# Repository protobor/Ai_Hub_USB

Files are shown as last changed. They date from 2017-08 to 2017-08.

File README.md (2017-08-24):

fe1.1s hub
==========

cloned from https://github.com/acrobotic/Ai_Hub_USB

Fork
----

 * completely redesigned
 * added support for gang power control (tested, ok)
 * will correctly switch between bus power and external power (self powered signal is inverted)

Issues
------

 * MOSFET footprint is fu...., so to assembly you'll need to bend legs and solder it upside down;
 * Something wrong with milling for usb micro b connector;
 * Bus powered and self powered signals inverted.

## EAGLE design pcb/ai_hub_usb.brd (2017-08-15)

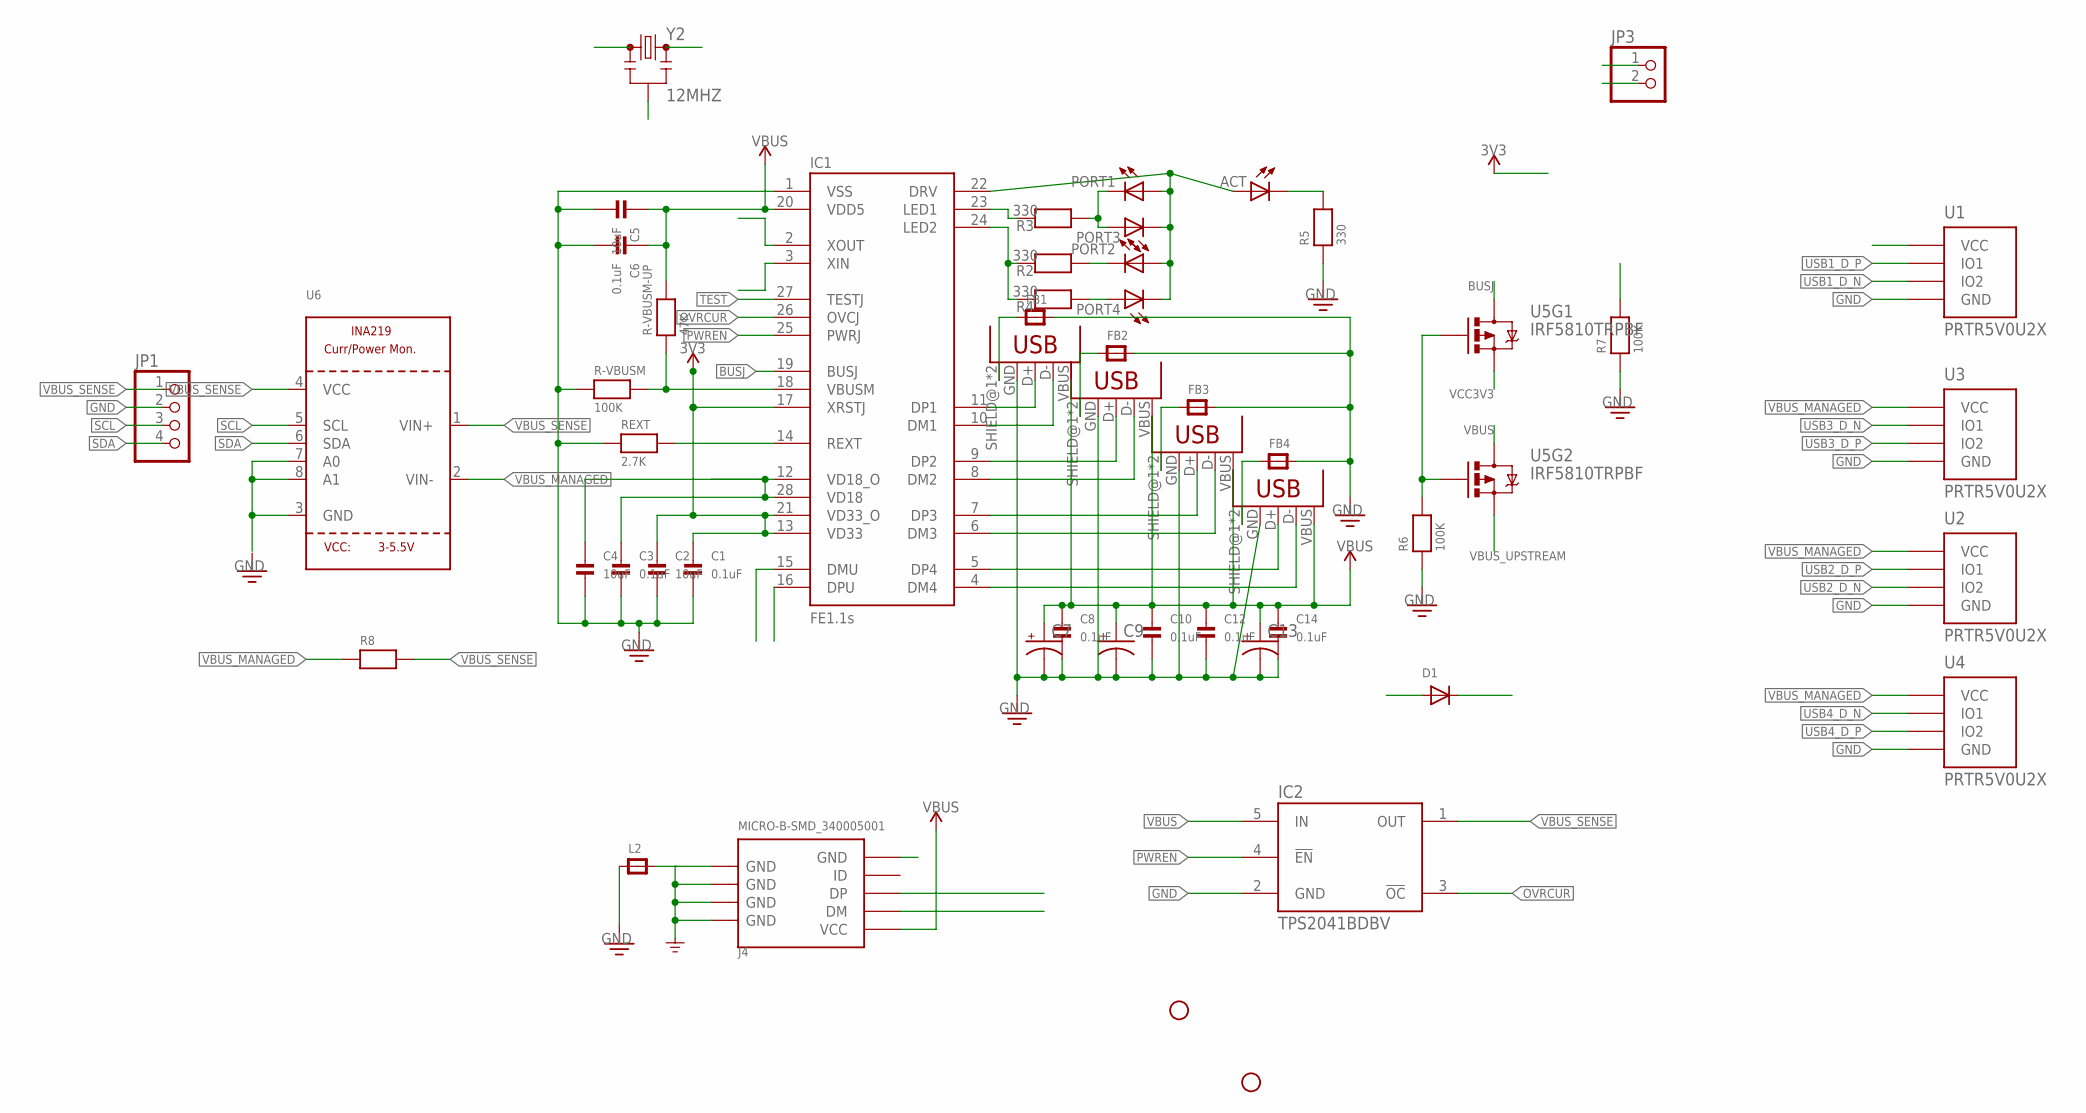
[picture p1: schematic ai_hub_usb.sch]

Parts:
ACT: LED0603; LED-0603
C1, C3, C6, C8, C10, C12, C14: 0.1uF; _0603MP
C2, C4, C5: 10uF; _0603MP
C7, C9, C13: CAP_POLD; PANASONIC_D
D1: DIODESMA; SMADIODE
FB1, FB2, FB3, FB4: FERRITE_0603MP; _0603MP
IC1: FE1.1S; FE1.1S_SSOP-28
IC2: TPS2041BDBV; SOT23-5L
J4: MICRO-B-SMD_340005001; MICRO-USB
JP1: HEADER-1X4ROUND; 1X04_ROUND
JP3: HEADER-1X2ROUND; 1X02_ROUND
L2: FERRITE_0603MP; _0603MP
PORT1, PORT2, PORT3, PORT4: LED0603; LED-0603
R2, R3, R4, R5: 330; _0603MP
R6, R7: 100K; _0603MP
R8: RESISTOR1206; 1206
R-VBUSM: 100K; _0603MP
R-VBUSM-UP: 47K; _0603MP
REXT: 2.7K; _0603MP
STANDOFF1, STANDOFF4: STAND-OFF4; STAND-OFF-4
U1, U2, U3, U4: PRTR5V0U2X; SOT-143B
U5: IRF5810TRPBF; SOT23-6
U6: INA219; SOT23-8
USB1, USB3, USB4: USBA-PTH-VERTICAL; USB-A-F-PTH-VERTICAL
USB2: USBA-PTH; USB-A-F-PTH
Y2: 12MHZ; RESONATOR-SMD

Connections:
BUSJ: IC1.19 (BUSJ), R7.2, U5.6 (D)
DRV: ACT.A, IC1.22 (DRV), PORT1.A, PORT2.A, PORT3.C, PORT4.C
GND: C1.2, C2.2, C3.2, C4.2, C5.2, C6.2, C7.-, C8.2, C9.-, C10.2, C12.2, C13.-, C14.2, FB1.2, FB2.2, FB3.2, FB4.2, IC1.1 (VSS), IC2.2 (GND), J4.5 (GND), JP1.2, JP3.2, L2.1, R5.1, R6.1, R7.1, R-VBUSM.1, REXT.1, U1.1 (GND), U2.1 (GND), U3.1 (GND), U4.1 (GND), U6.3 (GND), U6.7 (A0), U6.8 (A1), USB1.GND, USB2.GND, USB3.GND, USB4.GND, Y2.2
LED1: IC1.23 (LED1), R3.1
LED2: IC1.24 (LED2), R2.1, R4.1
unnamed: IC1.14 (REXT), REXT.2
unnamed: FB1.1, USB1.SHIELD@1 (SHIELD), USB1.SHIELD@2 (SHIELD)
unnamed: FB2.1, USB2.SHIELD@1 (SHIELD), USB2.SHIELD@2 (SHIELD)
unnamed: FB3.1, USB3.SHIELD@1 (SHIELD), USB3.SHIELD@2 (SHIELD)
unnamed: FB4.1, USB4.SHIELD@1 (SHIELD), USB4.SHIELD@2 (SHIELD)
unnamed: PORT2.C, R2.2
unnamed: PORT4.A, R4.2
unnamed: PORT1.C, PORT3.A, R3.2
unnamed: ACT.C, R5.2
OSC_IN: IC1.3 (XIN), Y2.1
OSC_OUT: IC1.2 (XOUT), Y2.3
OVRCUR: IC1.26 (OVCJ), IC2.3 (!OC)
PWREN: IC1.25 (PWRJ), IC2.4 (!EN)
SCL: JP1.3, U6.5 (SCL)
SDA: JP1.4, U6.6 (SDA)
TEST: IC1.27 (TESTJ)
USB1_D_N: IC1.10 (DM1), U1.3 (IO2), USB1.D-
USB1_D_P: IC1.11 (DP1), U1.2 (IO1), USB1.D+
USB2_D_N: IC1.8 (DM2), U2.3 (IO2), USB2.D-
USB2_D_P: IC1.9 (DP2), U2.2 (IO1), USB2.D+
USB3_D_N: IC1.6 (DM3), U3.2 (IO1), USB3.D-
USB3_D_P: IC1.7 (DP3), U3.3 (IO2), USB3.D+
USB4_D_N: IC1.4 (DM4), U4.2 (IO1), USB4.D-
USB4_D_P: IC1.5 (DP4), U4.3 (IO2), USB4.D+
USB_D_N: IC1.15 (DMU), J4.2 (DM)
USB_D_P: IC1.16 (DPU), J4.3 (DP)
USB_SHIELD: J4.S1 (GND), J4.S2 (GND), J4.S3 (GND), J4.S4 (GND), J4.S5 (GND), J4.S6 (GND), L2.2
VBUS: C5.1, C6.1, D1.C, IC1.20 (VDD5), IC2.5 (IN), R-VBUSM-UP.2, U5.4 (D)
VBUS_MANAGED: C7.+, C8.1, C9.+, C10.1, C12.1, C13.+, C14.1, R8.1, U1.4 (VCC), U2.4 (VCC), U3.4 (VCC), U4.4 (VCC), U6.2 (VIN-), USB1.VBUS, USB2.VBUS, USB3.VBUS, USB4.VBUS
VBUS_MONITOR: IC1.18 (VBUSM), R-VBUSM.2, R-VBUSM-UP.1
VBUS_SENSE: IC2.1 (OUT), JP1.1, R8.2, U6.1 (VIN+), U6.4 (VCC)
VBUS_UPSTREAM: J4.1 (VCC), U5.2 (S)
VCC1V8: C3.1, C4.1, IC1.12 (VD18_O), IC1.28 (VD18)
VCC3V3: C1.1, C2.1, IC1.13 (VD33), IC1.17 (XRSTJ), IC1.21 (VD33_O), U5.5 (S)
VEXT: D1.A, JP3.1, R6.2, U5.1 (G), U5.3 (G)

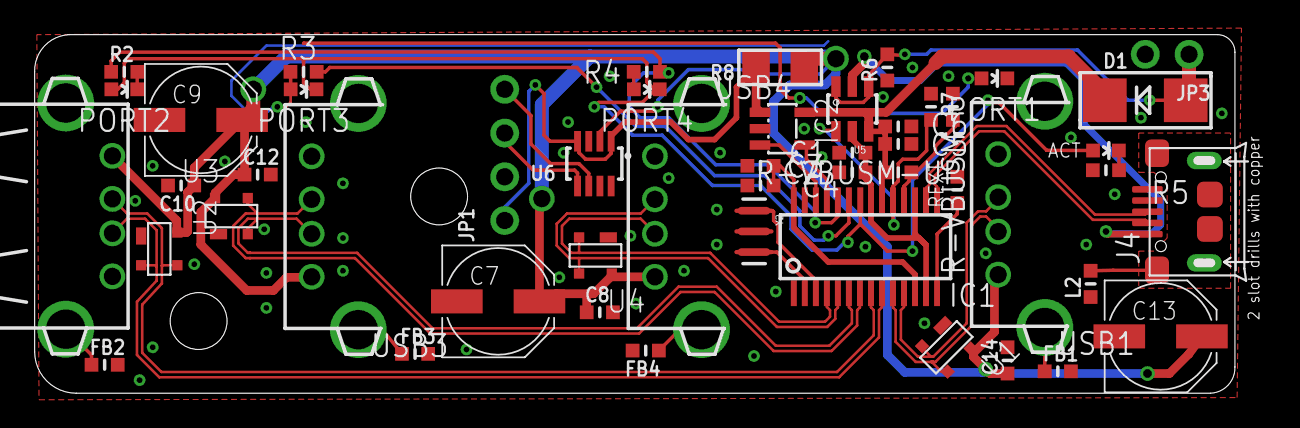
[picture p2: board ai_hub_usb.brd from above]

Board: 2 copper layers, 70.5 x 20.8 mm, 52 parts (0 on the bottom side), 39 nets.

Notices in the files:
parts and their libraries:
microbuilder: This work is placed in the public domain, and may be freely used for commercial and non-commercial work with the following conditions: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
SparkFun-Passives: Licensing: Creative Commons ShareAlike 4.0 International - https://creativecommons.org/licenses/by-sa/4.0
